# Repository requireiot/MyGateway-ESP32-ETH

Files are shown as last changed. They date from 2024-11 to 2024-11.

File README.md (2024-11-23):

MySensors Ethernet Gateway with ESP32
====

- [MySensors Ethernet Gateway with ESP32](#mysensors-ethernet-gateway-with-esp32)
  - [Objective](#objective)
  - [Features](#features)
  - [Building the Ethernet ESP32 gateway](#building-the-ethernet-esp32-gateway)
    - [Development environment](#development-environment)
    - [Installation](#installation)
    - [Hardware](#hardware)
  - [Modifications to the MySensors library](#modifications-to-the-mysensors-library)
    - [ESP32 gateway via Ethernet](#esp32-gateway-via-ethernet)
    - [Separate tasks for `loop()` and `_process()`](#separate-tasks-for-loop-and-_process)
    - [Connecting the RF24 radio module](#connecting-the-rf24-radio-module)
    - [New notification functions](#new-notification-functions)

## Objective

I needed a gateway that does not depend on a reliable WiFi connection, so Ethernet 
was the only option.

The MySensors website has instructions for how to build an _Ethernet_-based gateway 
(with an ATmega processor) or a gateway using an ESP8266 or ESP32 processor 
(with WiFi connection), but the combination of ESP32 processor and Ethernet connection 
requires some tweaks to the MySensors library, as I found out.

The ESP32 processor is already designed to be used with Ethernet, using a LAN8720 
interface module, which is available from Aliexpress etc. for under €3. This combination 
is well supported by the Arduino universe and the _ETH_ library. To work properly, 
the module needs one minor modification, as described [here](https://mischianti.org/integrating-lan8720-with-esp32-for-ethernet-connectivity-with-plain-http-and-ssl-https/) 
or [here](https://sautter.com/blog/ethernet-on-esp32-using-lan8720/).

## Features

The firmware implements 
* a MySensors _gateway_, that translates between RF24 messages and MQTT messages, 
  like the [example sketch](https://www.mysensors.org/apidocs/GatewayESP32_8ino_source.html) from the MySensors library, or
* a MySensors _repeater_, which re-transmits RF24 messages from a node to the gateway 
  and vice versa

In addition, there are a couple of additional features:

* a simple **Web UI** showing basic information about the device, and statistics 
  about message traffic:
  * IP address and hostname
  * (for a repeater) MySensors Node ID, and the Node ID of the parent
  * Automatic Retry Count (ARC) statistics: the number P of messages sent, the number R 
  of retries needed to succeed, and the "success rate" S = P/(P+R) in percent
  * the total number of messages sent and received, and the number or errors that 
  could not be recovered
  * (for a gateway) the total number of messages sent to and received from the controller
  * finally, a table of the number of messages received from each node, as a total tally, 
  and as an average rate (messages/hour), as well as the "success rate" (see above) for sending messages to each node id
* **over-the-air firmware update** is supported using the standard `ArduinoOTA`library
* an optional **DS18B20 temperature sensor** can be read and reported via MQTT, 
  if (like me) you have concerns about the temperature inside the plastic case of the device.
* A remote **Syslog** message can be sent on startup, which contains
  * code version information
  * IP and MAC address of the unit
  * the reset reason as reported by the ESP firmware

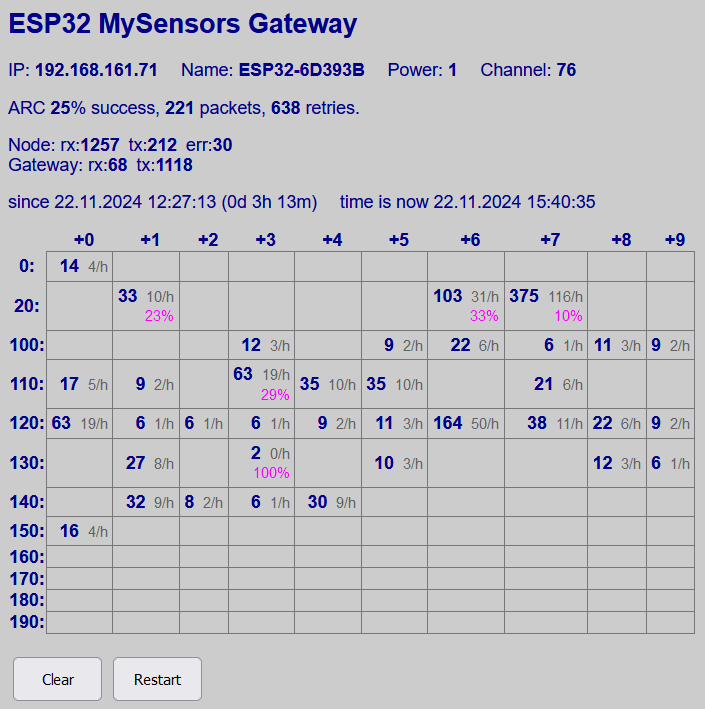
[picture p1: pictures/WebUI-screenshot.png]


Example screenshot from the gateway on my MySensors network. In the table, total number of messages received in **bold**, average number of messages received per hour in gray, and success rate for sending messages to a node in pink.

## Building the Ethernet ESP32 gateway

### Development environment

My development environment consists of Visual Studio Code with the Platformio plugin, 
I don't use the Arduino IDE.

### Installation

1. Clone the repository to your computer
2. copy `src/secrets.sample.h` to `src/secrets.h` and enter your WiFi network name 
   and password there
3. edit `platformio.ini` and set COM port names and IP addresses for your system. (I defined environments for three devices, called esp32-P, esp32-Q and esp32-S, for flashing via a serial interface, and via OTA. Your setup will be different.)
4. at the very start of the `src/main.cpp`, look at the `USE_xxx` constants 
  that enable each feature, comment out the ones you don't want.
5. near the start of `src/main.cpp`, look for the section that starts with 
   `#pragma region configuration` and adjust parameters as needed, e.g. the URL of your syslog server (if you have one), the URL of the MQTT broker, etc.

### Hardware

Schematics are [here](hardware/MyRepeater-ESP32-ETH.pdf). I didn't design 
a PCB, just built the Ethernet version on a prototype board with an ESP32 module 
footprint (called "_7x9cm Prototype PCB For ESP8266 ESP32_" on Aliexpress).

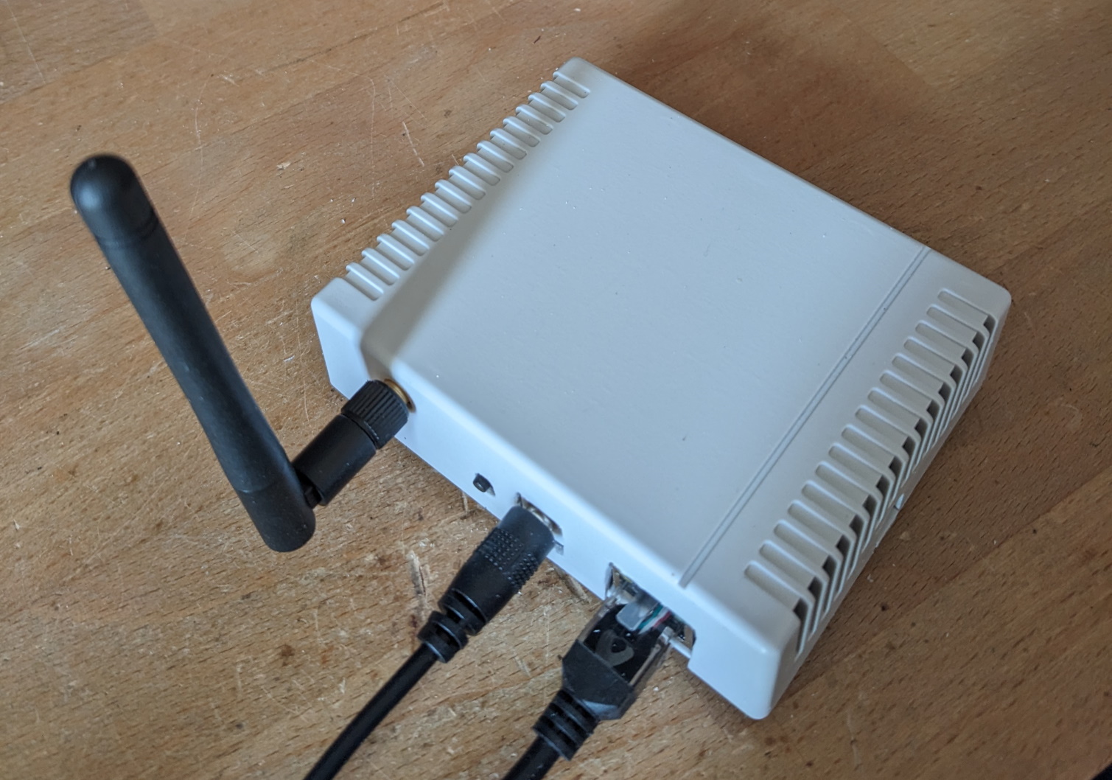
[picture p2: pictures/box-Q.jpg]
 
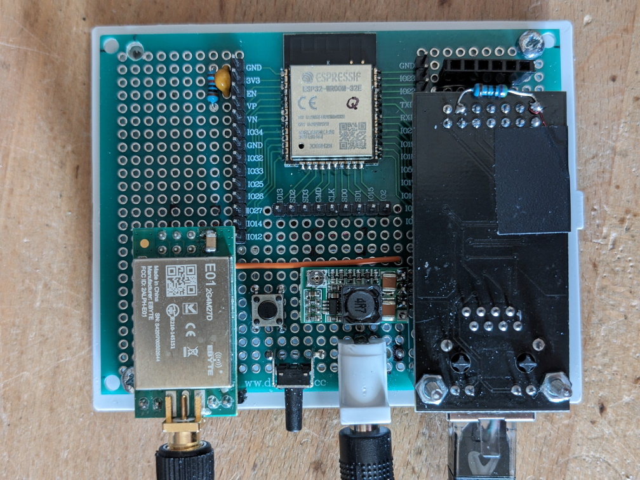
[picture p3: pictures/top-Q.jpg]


The gateway sits next to a Fritzbox 7490 router/DSL modem, connected by a short 
Ethernet cable, and powered from one of the USB ports of the router.

For a small WiFi-based repeater, I used a "mini" module on a piece of normal prototype 
board, placed in a wall wart housing (Reichelt P/N SSG 200 SK-I).

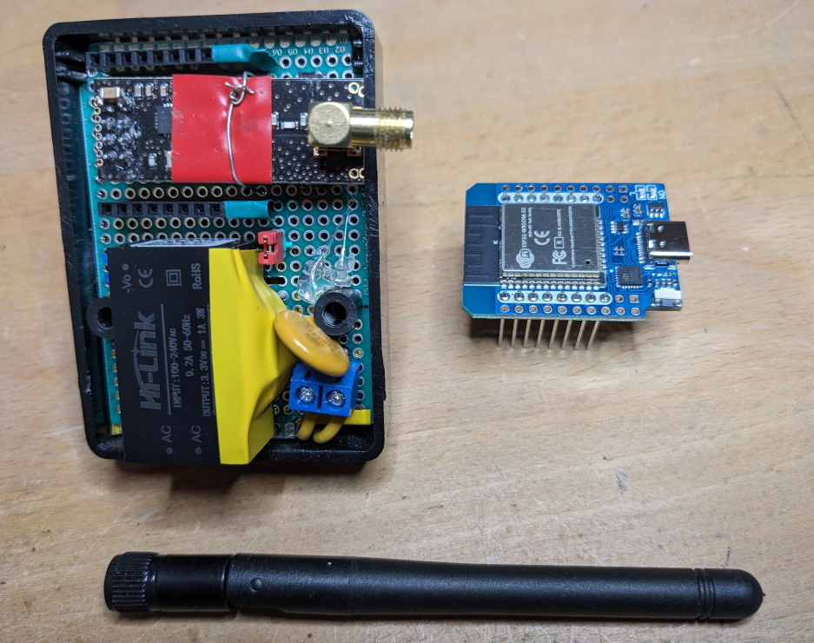
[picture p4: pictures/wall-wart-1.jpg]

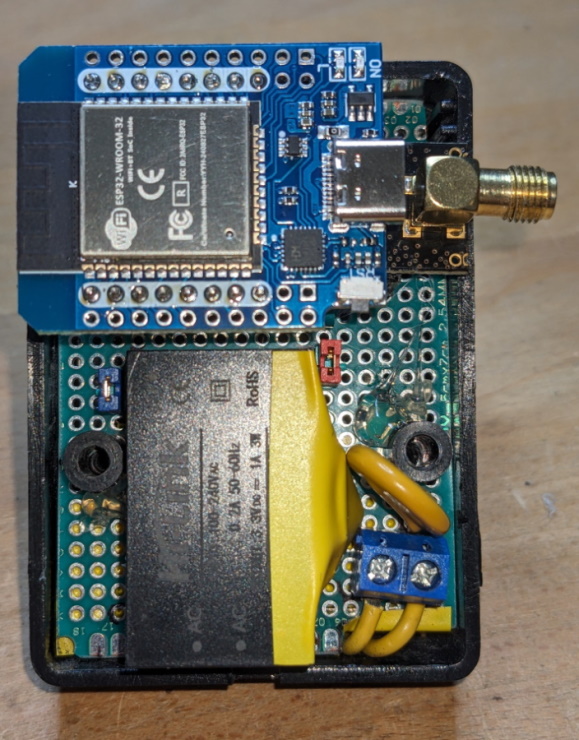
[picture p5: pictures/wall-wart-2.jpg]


## Modifications to the MySensors library

### ESP32 gateway via Ethernet
The MySensors library (version 2.3.2) already contains provisions for an ESP32 based 
gateway, just `#define MY_GATEWAY_ESP32`, and off you go, they even provide an 
[example sketch](https://www.mysensors.org/apidocs/GatewayESP32_8ino_source.html). 
However ... this assumes that the network connection will be via _WiFi_, there is 
no support for a wired Ethernet connection, as far as I can tell.

With my modified version of the MySensors library (included in this repository), 
you either `#define MY_GATEWAY_ESP32_WIFI`, and you get the same behavior as in 
the original, or you `#define MY_GATEWAY_ESP32_ETHERNET` to support a LAN8720 based 
Ethernet interface.

The Ethernet interface must be initialized in _application_ code, ideally before 
the MySensors stuff runs. A good place for this is the `preHwInit()` function 
declared by MySensors as a "weak" function, i.e. it is called early during startup 
if the function is defined in your code, but no error is thrown if you don't define 
a function with this name. See the source code for more details.

### Separate tasks for `loop()` and `_process()`
There are two functions that get called repeatedly during normal operation:
* the Arduino  `loop()` function, which handles all the features implemented by the application
* the MySensors `_process()` function, which handles RF24 communication ... which 
 normally gets called "invisibly" by the MySensors framework

I got the impression that the gateway or repeater runs more reliably (especially 
at lower CPU clock frequencies) if the two functions run in separate tasks, 
so extended calculations or waiting operations in `loop()` won't interfere with 
the regular polling for incoming RF24 packets. 

With my modification to the MySensors library included here, they run in separate 
tasks if the `MY_SEPARATE_PROCESS_TASK` preprocessor macro is defined, e.g. in 
the `platformio.ini` file. Note that both tasks run on the same ESP32 core, the 
other core remains dedicated to networking stuff.

When using separate tasks, the repeater or gateway will work reliably down to 40 MHz CPU frequency (using Ethernet) or 80 MHz (using WiFi).

### Connecting the RF24 radio module

Using the ESP32 Ethernet interface also affects how the NRF24 radio module can be 
connected. You can't use the default SPI port with its default pins on the ESP32, 
because some of those pins are occupied by the Ethernet interface, which, unlike 
other peripherals of the ESP like I2C or SPI, can't have its signals remapped to 
pins of your choice.

Instead of using the default SPI port, a.k.a. SPI3 or SPI(VSPI), we use the "other" 
SPI available on the ESP32, a.k.a. SPI2 or SPI(HSPI). Before you `#include <MySensors.h>`, just say
```
 SPIClass hspi(HSPI);   
 #define RF24_SPI hspi
```
This implies pins MISO=12, MOSI=13, SCK=14, CS=15. I also modified the MySensors 
library so you can `#define` macros named `MY_RF24_MISO_PIN`, `MY_RF24_MOSI_PIN`, 
`MY_RF24_SCK_PIN` and `MY_RF24_CS_PIN`, and the SPI interface will use those custom 
pins if those macros are defined in user code.

### New notification functions
To enable the statistics display, my code must be notified imediately after a message 
has been received (so I can count incoming messages), and after a message has been sent 
(so I can count them, and ask about the number of retries required to successfully 
deliver the message).

Function `void previewMessage(const MyMessage &message)` is called by the modified 
MySensors library right after a message has been received.

Function `void aftertransportSend(const uint8_t nextRecipient, const MyMessage &message)` 
is called by the modified MySensors library right after a message has been sent.

Both functions are declared in the library with the `weak` attribute, i.e. they are 
called if they are defined in the application code, and nothing happens if they are 
not defined in the application code.

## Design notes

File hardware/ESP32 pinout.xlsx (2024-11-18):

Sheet: Sheet1
 |  |  |  |  |  |  |  | WROOM Module
 |  |  |  |  |  |  | GND | Antenna | GND
 |  |  |  |  |  |  | 3V3 |  | io23 | pullup |  | VSPI-MOSI |  | ETH-MDC | ok for GPIO
 |  |  |  |  |  |  | EN |  | io22 | pullup |  | SCL |  | ETH-TX1 | ok for GPIO
 |  | RTC io0 |  |  | ADC1_0 | inp only | io36,VP |  | TxD0
 |  | RTC io3 |  |  | ADC1_3 | inp only | io39,VN |  | RxD0
 |  | RTC io4 |  |  | ADC1_6 | inp only | io34 |  | io21 | pullup |  | SDA |  | ETH-TXEN | ok for GPIO
 |  | RTC io5 |  |  | ADC1_7 | inp only | io35 |  | nc
ok for GPIO |  | RTC io9 | Touch 9 |  | ADC1_4 | no pu | io32 |  | io19 | pullup |  | VSPI-MISO |  | ETH-TX0 | ok for GPIO
ok for GPIO | DS18B20 | RTC io8 | Touch 8 |  | ADC1_5 | no pu | io33 |  | io18 | pullup |  | VSPI-SCK |  | ETH-MDIO | ok for GPIO
ok for GPIO | ETH-RX0 | RTC io6 |  | DAC 1 | ADC2_8 | no pu | io25 |  | io5 | pull-up |  | VSPI-SS |  |  | strapping pin
ok for GPIO | ETH-RX1 | RTC io7 |  | DAC 2 | ADC2_9 | no pu | io26 |  | io17 | pullup |  | TxD 2 |  |  | ok for GPIO | PSRAM SCLK, def Arduino RF24_CE
ok for GPIO | ETH-CRS | RTC io17 | Touch 7 |  | ADC2_7 | no pu | io27 |  | io16 | pullup |  | RxD 2 |  |  | ok for GPIO | PSRAM CE#
output signal at boot | NRF24-SCK | RTC io16 | Touch 6 | MTMS, HSPI-SCK | ADC2_6 | pullup | io14 |  | io4 | pull-down | ADC2_0 |  | Touch 0 | ETH-NC | ok for GPIO
strapping pin | NRF24-MISO | RTC io15 | Touch 5 | MTDI, HSPI-MISO | ADC2_5 | pull-down | io12 |  | io0 | pull-up | ADC2_1 |  | Touch 1 | ETH-REFCLK
 |  |  |  |  |  |  | GND |  | io2 | pull-down | ADC2_2 |  | Touch 2 | NRF24-CE | float or LOW to flash
ok for GPIO | NRF24-MOSI | RTC io14 | Touch 4 | MTCK, HSPI-MOSI | ADC2_4 | pull-down | io13 |  | io15 | pull-up | ADC2_3 | MTDO, HSPI-SS | Touch 3 | NRF24-CS | output signal at boot
 |  |  |  | Flash |  |  | io9 |  | io8 |  |  | Flash
 |  |  |  | Flash |  |  | io10 |  | io7 |  |  | Flash
 |  |  |  | Flash |  |  | io11 |  | io6 |  |  | Flash
 |  |  |  |  |  |  |  |  |  |  |  |  |  | italic : cannot be reassigned
 |  |  |  |  |  |  | Serial 1 default 12,14 must remap
 |  |  |  |  |  |  | Serial 2 default 16,17 can remap

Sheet: I2S
Device | I2C SCL | I2C SDA | mic | mic MCLK | mic BCLK | mic WS | mic DI | I2C addr | spk | spk MCLK | spk BCLK | spk WS | spk DO | I2C addr | AMP ctrl | comments
Inmp441 Max98357a FastLed |  |  | INMP441 |  | 25 | 32 | 33 |  | MAX98357A |  | 14 | 12 | 27
AudioKit | 32 | 33 | ES8388 |  | 27 | 25 |  | 16 | ES8388 |  | 27 | 25 | 26 | 16 | 21 | ESP32A1S V2.2+ variant 1 (ES8388)
ESP32-S3-Box-lite | 18 | 8 | ES7243E | 2 | 17 | 47 | 16 | 16 | ES8156 | 2 | 17 | 47 | 15 | 8 | 46
ESP32-S3-Box | 18 | 8 | ES7210 | 2 | 17 | 47 | 16 |  | ES8311 | 2 | 17 | 47 | 15 | 0x40 | 46

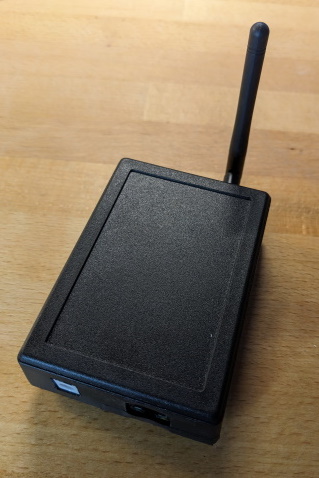
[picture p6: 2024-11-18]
pictures/box-P.jpg

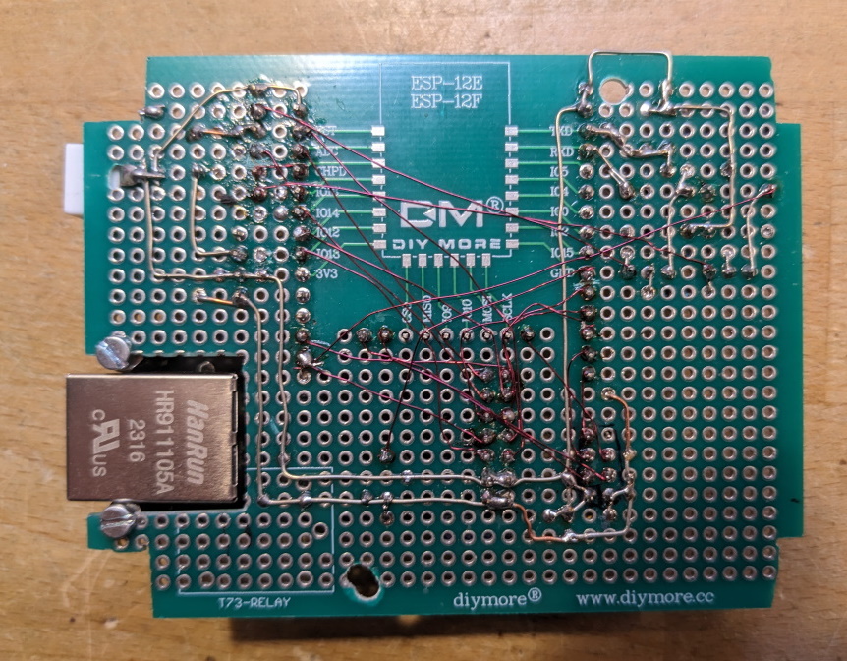
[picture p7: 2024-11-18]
pictures/bottom.jpg

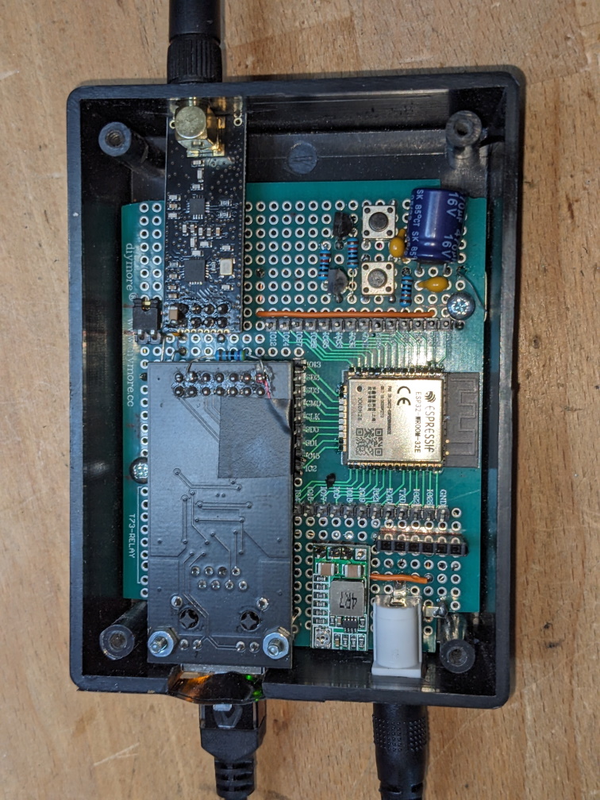
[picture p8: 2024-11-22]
pictures/top-P.jpg

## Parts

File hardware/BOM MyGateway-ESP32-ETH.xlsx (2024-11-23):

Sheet: ETH Gateway «P»
 |  |  |  |  | 11.52 €
 | Price/lot | units/lot | price/unit | units | price
Case 109 x 79 x 32 mm | 2.00 € | 1 | 2.20 € | 1 | 2.20 € | Reichelt 4U32110803000
Prototype PCB 7x9 for ESP | 1.56 € | 1 | 1.56 € | 1 | 1.56 € | Aliexpress "70X90mm Prototype PCB Breadboard Board For ESP"
ESP32 WROOM | 2.36 € | 1 | 2.36 € | 1 | 2.36 € | Aliexpress "ESP32-WROOM-32E"
NRF24L01+ PA LNA | 1.83 € | 1 | 1.83 € | 1 | 1.83 € | Aliexpress https://de.aliexpress.com/item/32330779943.html
LAN8720 Module | 2.35 € | 1 | 2.35 € | 1 | 2.35 € | Aliexpress "Smart Electronics LAN8720 Module, Straight needle"
Female pin header 2x7 | 2.79 € | 400 | 0.01 € | 14 | 0.10 € | Aliexpress
DC-DC converter | 0.64 € | 1 | 0.64 € | 1 | 0.64 € | Aliexpress "Mini DCDC converter 1.8V 2.5V 3.3V 5V 9V 12V"
Barrel jack 5.5/2.1mm print | 1.08 € | 10 | 0.11 € | 1 | 0.11 € | Aliexpress "10PCS Hot Sale DC-005 DC Power Jack Socket5.5x2.1mm"
DS18B20 | 2.49 € | 10 | 0.25 € | 1 | 0.25 € | Aliexpress "DALLAS DS18B20 TO-92 IC Temperature Sensor"
Capacitor 470µF 16V radial | 0.90 € | 10 | 0.09 € | 1 | 0.09 € | Reichelt "RAD 470/16"
Capacitor 100µF 50V SMD 1206 | 2.59 € | 100 | 0.03 € | 1 | 0.03 € | Aliexpress "100pcs 1206 Ceramic Capacitor 50V SMD Thick Film Chip Multilayer 100uF"
Capacitor 100nF 50V SMD 1206 | 0.88 € | 100 | 0.01 € | 1 | 0.01 € | Aliexpress "100pcs 1206 SMD Chip Multilayer Ceramic Capacitor 100nF 50V"

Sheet: WiFi Repeater
 |  |  |  |  | 14.77 €
 | Price/lot | units/lot | price/unit | units | price
Wall wart case | 6.95 € | 1 | 6.95 € | 1 | 6.95 € | Reichelt SSG 200 SK-I
Prototype PCB 4x6cm | 1.43 € | 5 | 0.29 € | 1 | 0.29 € | Aliexpress "Double side Prototype PCB Tinned Universal board 4x6 4*6cm"
D1 Mini ESP32 | 2.59 € | 1 | 2.59 € | 1 | 2.59 € | Aliexpress "D1 MINI ESP32 WiFi+Bluetooth ESP-32 CH9102"
NRF24L01+ PA LNA | 1.83 € | 1 | 1.83 € | 1 | 1.83 € | Aliexpress https://de.aliexpress.com/item/32330779943.html
AC-DC HLK-PM03 | 2.20 € | 1 | 2.20 € | 1 | 2.20 € | Aliexpress "HLK-PM03 (3.3V 3W)"
Female pin header 2x10 | 2.79 € | 400 | 0.01 € | 20 | 0.14 € | Aliexpress
Varistor S14K250 | 0.29 € | 1 | 0.29 € | 1 | 0.29 € | Pollin 94‑221092
Thermo fuse 73°C | 0.48 € | 1 | 0.48 € | 1 | 0.48 € | Pollin 94‑260240

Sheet: ETH Repeater «Q»
 |  |  |  |  | 11.27 €
 | Price/lot | units/lot | price/unit | units | price
Case 109 x 79 x 32 mm | 1.69 € | 1 | 2.20 € | 1 | 2.20 € | Aliexpress "Enclosure Case Plastic Box Circuit Board Project 100x80x29mm, WHITE"
Prototype PCB 7x9 for ESP | 1.56 € | 1 | 1.56 € | 1 | 1.56 € | Aliexpress "70X90mm Prototype PCB Breadboard Board For ESP"
ESP32 WROOM | 2.36 € | 1 | 2.36 € | 1 | 2.36 € | Aliexpress "ESP32-WROOM-32E"
NRF24L01+ PA LNA | 1.83 € | 1 | 1.83 € | 1 | 1.83 € | Aliexpress https://de.aliexpress.com/item/32330779943.html
LAN8720 Module | 2.35 € | 1 | 2.35 € | 1 | 2.35 € | Aliexpress "Smart Electronics LAN8720 Module, Straight needle"
Female pin header 2x7 | 2.79 € | 400 | 0.01 € | 14 | 0.10 € | Aliexpress
DC-DC converter | 0.64 € | 1 | 0.64 € | 1 | 0.64 € | Aliexpress "Mini DCDC converter 1.8V 2.5V 3.3V 5V 9V 12V"
Barrel jack 5.5/2.1mm print | 1.08 € | 10 | 0.11 € | 1 | 0.11 € | Aliexpress "10PCS Hot Sale DC-005 DC Power Jack Socket5.5x2.1mm"
Capacitor 470µF 16V radial | 0.90 € | 10 | 0.09 € | 1 | 0.09 € | Reichelt "RAD 470/16"
Capacitor 100µF 50V SMD 1206 | 2.59 € | 100 | 0.03 € | 1 | 0.03 € | Aliexpress "100pcs 1206 Ceramic Capacitor 50V SMD Thick Film Chip Multilayer 100uF"
Capacitor 100nF 50V SMD 1206 | 0.88 € | 100 | 0.01 € | 1 | 0.01 € | Aliexpress "100pcs 1206 SMD Chip Multilayer Ceramic Capacitor 100nF 50V"

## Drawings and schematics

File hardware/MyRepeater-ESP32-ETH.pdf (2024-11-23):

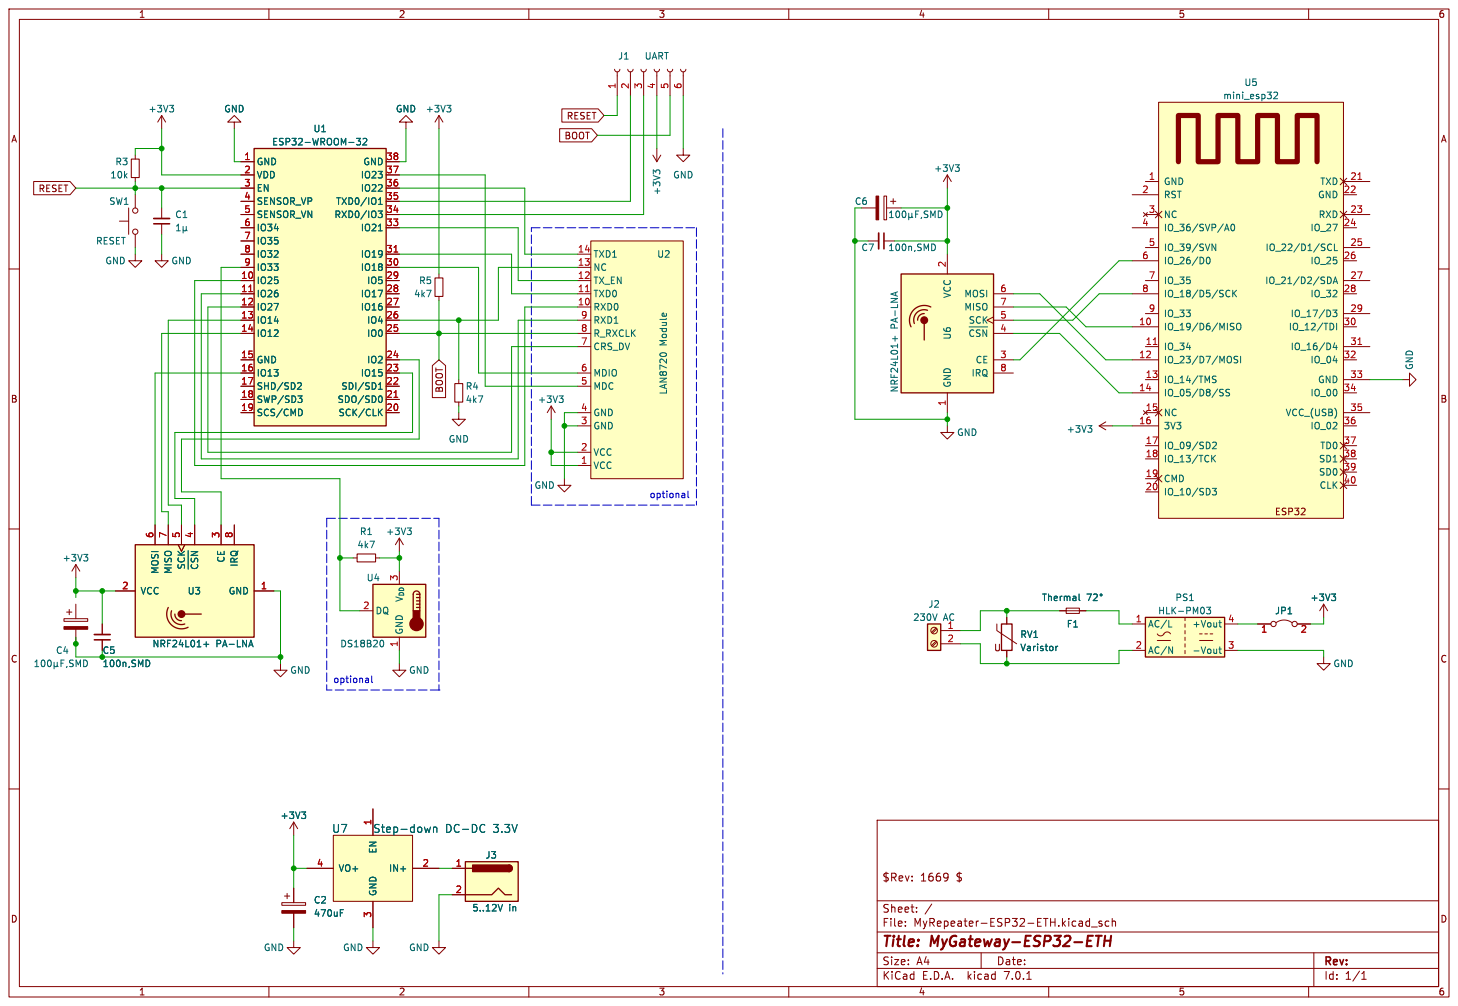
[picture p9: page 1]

2 CE 3 ~{CSN}4 SCK 5 MOSI 6 MISO 7

3 VO+ 4 U7 Step-down DC-DC 3.3V

Id: 1/1 Title: MyGateway-ESP32-ETH

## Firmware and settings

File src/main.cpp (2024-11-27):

/**
 * @file 		  main.cpp
 *
 * Project		: Home automation
 * Author		: Bernd Waldmann
 * Created		: 03-Oct-2024
 * Tabsize		: 4
 * 
 * This Revision: $Id: main.cpp 1684 2024-11-27 11:09:46Z  $
 */

/*
   Copyright (C) 2024 Bernd Waldmann

   This Source Code Form is subject to the terms of the Mozilla Public License, v. 2.0. 
   If a copy of the MPL was not distributed with this file, You can obtain one at http://mozilla.org/MPL/2.0/

   SPDX-License-Identifier: MPL-2.0
*/

/*
  Relies on MySensors, Created by Henrik Ekblad <henrik.ekblad@mysensors.org>.
  Note that the MySensors library is under GPL, so 
  - if you want to combine this source code file with the MySensors library 
    and redistribute it, then read the GPL to find out what is allowed.
  - if you want to combine this file with the MySensors library and only 
    use it at home, then read the GPL to find out what is allowed.
  - if you want to take just this source code, learn from it, modify it, and 
    redistribute it, independent from MySensors, then you have to abide by 
    my license rules (MPL 2.0), which imho are less demanding than the GPL.
 */

/**
 * @brief MySensors gateway or repeater, with ESP32 with LAN8720 Ethernet adapter
*/

//----- some configuration options
// these are defined in platformio.ini, they are specific to each device
// #define USE_ETHERNET    // use Ethernet with LAN8720 rather than WiFi
// #define USE_HSPI        // implies MISO=12 MOSI=13 SCK=14 SS=15
// #define USE_DS18B20     // use temperature sensor
// #define MY_SEPARATE_PROCESS_TASK // loop() and _process() in separate tasks

// these can be enabled here, they are common to all devices
#define USE_SYSLOG      // report to remote syslog server, URL see below
#define USE_NTP         // get time from time server, URL see below
#define USE_HTTP        // enable web UI
#define USE_OTA         // enable over-the-air firmware update

//----- uncomment either of these two, here or in platformio.ini
//#define OPERATE_AS_GATEWAY
//#define OPERATE_AS_REPEATER

//----- the Arduino universe
#include <Arduino.h>
#include <WiFi.h>
#ifdef USE_ETHERNET
 #include <ETH.h>                // LGPLv2.1+ license
#endif
#ifdef USE_SYSLOG
 #include <Syslog.h>             // MIT license, https://github.com/arcao/Syslog
#endif
#ifdef USE_NTP
 #include <NTPClient.h>          // MIT license, https://github.com/arduino-libraries/NTPClient
#endif
#ifdef USE_OTA
 #include <ArduinoOTA.h>         // LGPLv2.1+ license, https://github.com/jandrassy/ArduinoOTA
#endif
#ifdef USE_HTTP 
 #include <WebServer.h>        // LGPLv2.1+ license
#endif
#ifdef USE_DS18B20
 #include <OneWire.h>
 #include <DS18B20.h>           // MIT license, https://github.com/RobTillaart/DS18B20_RT
#endif

//----- the ESP-IDF universe
#include <rom/rtc.h>            // Apache-2.0 license
#include <esp32/clk.h>
#include <esp_pm.h>

//----- my headers
#include "ansi.h"
#include "Revision.h"   // automatically generated header file with SVN revision
#include "secrets.h"    // WiFi password etc

//=====================================================================
#pragma region configuration

// default to repeater operation, unless specified otherwise above or in platformio.ini)
#if !defined(OPERATE_AS_GATEWAY) && !defined(OPERATE_AS_REPEATER)
 #define OPERATE_AS_REPEATER
#endif

#ifdef USE_ETHERNET
 #define IF_NAME "ETH"
#else
 #define ETH WiFi
 #define IF_NAME "WiFi"
#endif

#if defined(USE_ETHERNET) && !defined(USE_HSPI)
 #define USE_HSPI
#endif

//----- pins for LAN8720 Ethernet module
#define PIN_ETH_PHY_POWER   4      // Pin# of the enable for the ext crystal osc, -1 to disable
#define PIN_ETH_PHY_MDC     23      // Pin# of the I²C SCL
#define PIN_ETH_PHY_MDIO    18      // Pin# of the I²C SDA

//----- pin connected to DS18B20 temperature sensor (optional)
#define PIN_DS18B20         33      

//----- pins for SPI connected to NRF24 module
#ifdef USE_HSPI
 #define MY_RF24_CE_PIN      2
 #define MY_RF24_MISO_PIN    12
 #define MY_RF24_MOSI_PIN    13
 #define MY_RF24_SCK_PIN     14
 #define MY_RF24_CS_PIN      15
#else
 #define MY_RF24_CE_PIN     26
 #define MY_RF24_MISO_PIN    19
 #define MY_RF24_MOSI_PIN    23
 #define MY_RF24_SCK_PIN     18
 #define MY_RF24_CS_PIN      5 
#endif

//----- Syslog
#define SYSLOG_SERVER "log-server"
#define SYSLOG_PORT 514
#define SYSLOG_APPNAME "main"

//----- OTA
#define OTA_PASSWORD "123"
#define OTA_PORT    3232

//----- NTP
#define NTP_SERVER  "fritz.box"

//----- MySensors MQTT (only applies to gateway mode)
#define MY_CONTROLLER_URL_ADDRESS "ha-server"
#define MY_MQTT_PUBLISH_TOPIC_PREFIX "my/E/stat"
#define MY_MQTT_SUBSCRIBE_TOPIC_PREFIX "my/cmnd"

#define VERSION "$Id: main.cpp 1684 2024-11-27 11:09:46Z  $ "

#ifdef LED_BUILTIN
 #define LED_INIT   pinMode(LED_BUILTIN,OUTPUT);
 #define TURN_LED_ON     digitalWrite(LED_BUILTIN,HIGH)
 #define TURN_LED_OFF    digitalWrite(LED_BUILTIN,LOW)
#else
 #define LED_INIT
 #define TURN_LED_ON
 #define TURN_LED_OFF
#endif

//---------------------------------------------------------------------
#pragma endregion
//=====================================================================
#pragma region Timing

#define SECONDS		* 1000uL
#define MINUTES 	* 60uL SECONDS
#define HOURS 		* 60uL MINUTES
#define DAYS		* 24uL HOURS

/// minimum time between comms statistics reports
const unsigned long MIN_REPORT_INTERVAL = 60 MINUTES;
/// time between temperature measurements
const unsigned long REPORT_TEMPERATURE_INTERVAL = 30 MINUTES;

//---------------------------------------------------------------------
#pragma endregion
//=====================================================================
#pragma region MySensors

// when using Ethernet, RF24 module must be connected via SPI(2) default pins, 
// because SPI(3) default pins used by LAN8720
#include <SPI.h>
#ifdef USE_HSPI
 SPIClass hspi(HSPI);   // implies MISO=12 MOSI=13 SCK=14 SS=15
 #define RF24_SPI hspi
#else
 SPIClass vspi(VSPI);   // implies MISO=12 MOSI=13 SCK=14 SS=15
 #define RF24_SPI vspi
#endif

#define MY_RADIO_RF24
// with NRF24-PA-LNA module with external antenna, use this setting
// otherwise, too much interference
#define MY_RF24_PA_LEVEL RF24_PA_LOW

#define MY_RF24_SPI_SPEED 1'000'000u
//#define MY_TRANSPORT_WAIT_READY_MS 3000 

// MySensors operating mode
//#define MY_DEBUG
//#define MY_DEBUG_VERBOSE_RF24
#define MY_INDICATION_HANDLER
#define MY_SPLASH_SCREEN_DISABLED

//----- operate as gateway
#ifdef OPERATE_AS_GATEWAY
 #ifdef USE_ETHERNET
  #define MY_GATEWAY_ESP32_ETHERNET
 #else
  #define MY_GATEWAY_ESP32_WIFI
 #endif
 #define MY_GATEWAY_MQTT_CLIENT
 #define FRIENDLY_PROJECT_NAME "ESP32 MySensors Gateway"
 #define NODE_ID_AS_SENSOR MY_NODE_ID
 #define MY_GATEWAY_MAX_CLIENTS 2
 //#define MY_RF24_CHANNEL 99    // test only
#endif

//----- operate as repeater
#ifdef OPERATE_AS_REPEATER
 #define MY_REPEATER_FEATURE
 #define FRIENDLY_PROJECT_NAME "ESP32 MySensors Repeater"
#endif

#include <MySensors.h>

#define SENSOR_ID_ARC		98
#define V_TYPE_ARC			V_VAR5
MyMessage arcMessage = MyMessage(SENSOR_ID_ARC, V_TYPE_ARC);

#define SENSOR_ID_CMND      96

#ifdef USE_DS18B20
 #define SENSOR_ID_TEMP 		41
 MyMessage msgTemperature(SENSOR_ID_TEMP, V_TEMP);
#endif

#define SENSOR_ID_HELLO     95
MyMessage msgHello(SENSOR_ID_HELLO, V_TEXT);

//---------------------------------------------------------------------
#pragma endregion
//=====================================================================
#pragma region Global variables

WiFiUDP udpClient;

#ifdef USE_SYSLOG
 Syslog syslog(udpClient, SYSLOG_SERVER, SYSLOG_PORT, "ESP32", SYSLOG_APPNAME, LOG_USER);
#endif

#ifdef USE_NTP
 NTPClient ntpClient(udpClient,NTP_SERVER);
#endif

#ifdef USE_HTTP 
 WebServer httpServer(80);
#endif

#ifdef USE_DS18B20
 OneWire ow(PIN_DS18B20);
 DS18B20 ds18b20(&ow);
 bool hasDS18B20 = false;
#endif

/// static buffer for assembling various messages
char msgbuf[256];


/// for counting indication() status notifications
struct RxTxStats_t {
	unsigned nRx, nTx, nGwRx, nGwTx, nErr;
} rxtxStats;

/// nMessagesRx[i] counts messages received from node id `i`
unsigned nMessagesRx[256];
/// nMessagesTx[i] counts messages sent to node id `i`
unsigned nMessagesTx[256];
/// nRetries[i] counts mretries required for messages sent to node id `i`
unsigned nRetries[256];

struct ArcStats_t {
    unsigned packets;   ///< number of packets sent
    unsigned retries;   ///< number of retries required
    unsigned success;   ///< success rate in percent
} arcStats;

const char* reset_reasons[] = {
"0: none",
"1: Vbat power on reset",
"2: unknown",
"3: Software reset digital core",
"4: Legacy watch dog reset digital core",
"5: Deep Sleep reset digital core",
"6: Reset by SLC module, reset digital core",
"7: Timer Group0 Watch dog reset digital core",
"8: Timer Group1 Watch dog reset digital core",
"9: RTC Watch dog Reset digital core",
"10: Instrusion tested to reset CPU",
"11: Time Group reset CPU",
"12: Software reset CPU",
"13: RTC Watch dog Reset CPU",
"14: for APP CPU, reseted by PRO CPU",
"15: Reset when the vdd voltage is not stable",
"16: RTC Watch dog reset digital core and rtc module"
};

time_t t_last_clear = 0;

time_t getTimeNow()
{
#ifdef USE_NTP
    return ntpClient.getEpochTime();
#else
    return time(nullptr);
#endif
}

//---------------------------------------------------------------------
#pragma endregion
//=====================================================================
#pragma region ARC statistics

/**
 * @brief Collect statistics re Automatic Retries Count (ARC) for RF24.
 * Call this function immediately after each `send()` call.
 * 
 * @return int  number of retries required for most recent send
 * 
 */
int collectArcStatistics()
{
	int rssi = transportHALGetSendingRSSI();	// boils down to (-29 - (8 * (RF24_getObserveTX() & 0xF)))
	int arc = (-(rssi+29))/8;
	arcStats.packets++;         // # of packets sent
	arcStats.retries += arc;    // # of retries required
    arcStats.success = 
        arcStats.packets ? 
            (100uL * arcStats.packets) / (arcStats.packets + arcStats.retries) 
            : 100;
    return arc;
}


/**
 * @brief Reset all statistics counters to zero. Do this every hour or so
 * 
 */
void initStats()
{
	memset( nMessagesRx, 0, sizeof(nMessagesRx));
	memset( nMessagesTx, 0, sizeof(nMessagesTx));
	memset( nRetries, 0, sizeof(nRetries));
	memset( &rxtxStats, 0, sizeof(rxtxStats) );
    memset( &arcStats, 0, sizeof arcStats );
    t_last_clear = getTimeNow();
}


/**
 * @brief Send JSON-esque message with error statistics, then reset counters.
 * Error statistics include # of packets sent, # of retries required, success rate
 * Call this once per hour or so
 * 
 * @return const char* pointer to string sent to MySensors, like "{P:100;R:10;S:90}"
 *
 * Success rate:
 * 5 packets 0 retries = 100%
 * 5 packets 5 retries = 50%
 * 5 packets 20 retries = 20%
 */
const char* reportArcStatistics()
{
	//              				    1...5...10...15...20...25 max payload
	//				                    |   |    |    |    |    |
	static char payload[26];	//      {P:65535;R:65535;S:100}
	snprintf(payload, sizeof payload, "{P:%u,R:%u,S:%u}",
        arcStats.packets, arcStats.retries, arcStats.success );

    //memset( &arcStats, 0, sizeof arcStats );
	arcMessage.setSensor(SENSOR_ID_ARC).setType(V_TYPE_ARC);
	delay(10);
    send(arcMessage.set(payload));
	return payload;
}

//---------------------------------------------------------------------
#pragma endregion
//=====================================================================
#pragma region OTA

#ifdef USE_OTA

void setupOTA()
{
//----- configure Over-The-Air updates
	ArduinoOTA.setPort( OTA_PORT );
	ArduinoOTA.setPassword( OTA_PASSWORD );
    ArduinoOTA.setHostname( ETH.getHostname());
    
	ArduinoOTA.onStart([]() {
		Serial.println("ArduinoOTA start");
	});
	ArduinoOTA.onEnd([]() {
		Serial.println("\nArduinoOTA end");
	});
	ArduinoOTA.onProgress([](unsigned int progress, unsigned int total) {
		Serial.printf("OTA Progress: %u%%\r", (progress / (total / 100)));
	});
	ArduinoOTA.onError([](ota_error_t error) {
		Serial.printf("Error[%u]: ", error);
		if (error == OTA_AUTH_ERROR) {
			Serial.println("Auth Failed");
		} else if (error == OTA_BEGIN_ERROR) {
			Serial.println("Begin Failed");
		} else if (error == OTA_CONNECT_ERROR) {
			Serial.println("Connect Failed");
		} else if (error == OTA_RECEIVE_ERROR) {
			Serial.println("Receive Failed");
		} else if (error == OTA_END_ERROR) {
			Serial.println("End Failed");
		}
	});
	ArduinoOTA.begin();
}

#endif // USE_OTA

//---------------------------------------------------------------------
#pragma endregion
//=====================================================================
#pragma region Webserver

#ifdef USE_HTTP 


const char index_html[] PROGMEM = R"rawliteral(
<!DOCTYPE HTML><html>
<head>
  <title>%TITLE%</title>
  <style>
    body { background-color: #cccccc; font-family: Arial, Helvetica, Sans-Serif; Color: #000088; line-height: 1.1; }
    table { border-collapse: collapse; }
    td { text-align: right; border: 1px solid #777777; padding: 4px; }
    button { margin: 5px; padding:10px; min-height:20px; min-width: 80px; float:left; }
    .mph { color: #606060; font-size:smaller; }
    .suc { color: #fc03fc; font-size:smaller; }
  </style>
</head>
<body>
  <h2>%TITLE%</h2>
  <p>
    IP:<b>%IPADDR%</b>&emsp;
    Name:<b>%HOSTNAME%</b>&emsp;
    Channel:<b>%CHANNEL%</b>&emsp;
    Power:<b>%POWER%</b>&emsp;
)rawliteral"

#ifdef OPERATE_AS_REPEATER
 R"rawliteral(
    Node:<b>%NODEID%</b>&emsp;
    Parent:<b>%PARENT%</b>&emsp;
 )rawliteral"
#endif

R"rawliteral(
  </p>  
  <p>
    ARC <b>%SUCCESS%</b>%% success, <b>%PACKETS%</b> packets, <b>%RETRIES%</b> retries.&emsp;
  </p>
  <p>
    Node rx:<b>%NRX%</b>&ensp;tx:<b>%NTX%</b>&ensp;err:<b>%NERR%</b> (<b>%ERROR_RATE%</b>%%)&emsp;
)rawliteral"

#ifdef OPERATE_AS_GATEWAY
 R"rawliteral(
    Gateway: rx:<b>%NGWRX%</b>&ensp;tx:<b>%NGWTX%</b>
 )rawliteral"
#endif

R"rawliteral(
  </p>
  <p>
    since %LASTCLEAR% (%ELAPSED%)&emsp;
    time is now %NOW%
  </p>
  <p>%TABLE%</p>
  <form action="/clear"><button type="submit">Clear</button></form>
  <form action="/reboot"><button type="submit">Restart</button></form>
</body>
</html>
)rawliteral";


/**
 * @brief Convert unsigned int to string
 */
String utos( unsigned u )
{
    static char buf[10];
    utoa(u,buf,10);
    return String(buf);
}


/**
 * @brief Generate one HTML table row, #of messages received from nodes (y)..(y+9)
 * 
 * @param y 
 * @return String 
 */
String make_table_row(unsigned y, time_t nSecsElapsed)
{
    unsigned x, totalMsgsRx, MsgsPerHour, totalMsgsTx, totalRetries, success;

    String s = "<tr><th>" + utos(y) + ":</td>";
    for (x=0; x<10; x++) {

        totalMsgsRx = nMessagesRx[y + x];
        if (nSecsElapsed)
            MsgsPerHour = (totalMsgsRx * 3600uL) / nSecsElapsed;
        s += "<td>";
        if (totalMsgsRx > 0) {
            s += "<b>" + utos(totalMsgsRx) + "</b>";
            if (nSecsElapsed)
                s += "&ensp;<span class='mph'>" + utos(MsgsPerHour) + "/h</span>";
        }
        totalMsgsTx = nMessagesTx[y+x];
        if (totalMsgsTx > 0) {
            totalRetries = nRetries[y+x];
            success = (100 * totalMsgsTx) / (totalMsgsTx + totalRetries);
            s += "<br/><span class='suc'>" + utos(success) + "%</span>";
        }
        s += "</td>";
    }
    s += "</tr>\n";
    return s;
}


/**
 * @brief Generate HTML table with statistics (# of messages received per node)
 * 
 * @return String 
 */
String make_table() 
{
    String s;
    unsigned x,y;
    time_t nSecsElapsed = getTimeNow() - t_last_clear;

    s = "<table><tr><th> </th>";
    for (x=0; x<10; x++) s += "<th>&ensp;+" + utos(x) + "</th>";
    s += "</tr>\n";
    s += make_table_row(0,nSecsElapsed);
    s += make_table_row(20,nSecsElapsed);
    for (y=100; y<200; y+=10) {
        s += make_table_row(y,nSecsElapsed);
    }
    s += "</table>";
    return s;
}


/**
 * @brief Poor man's templating engine: replace keywords with content
 * 
 * @param var       the keyword that was enclosed in %...%
 * @return String   the replacement
 */
String processor(const String& var)
{
    if (var.length()==0) return "%";

    //----- static device information
    if (var=="IPADDR") return ETH.localIP().toString();
    if (var=="HOSTNAME") return ETH.getHostname();
    if (var=="NODEID") return String(MY_NODE_ID);
    if (var=="VERSION") return String(VERSION);
    if (var=="PARENT") return String(transportGetParentNodeId());
    //----- configuration
    if (var=="POWER") return String(MY_RF24_PA_LEVEL);
    if (var=="CHANNEL") return String(MY_RF24_CHANNEL);

    //-----indication-based counts
    // # of messages received via network
    if (var=="NRX") return String(rxtxStats.nRx);
    // # of messages sent via network
    if (var=="NTX") return String(rxtxStats.nTx);
    // # of messages failed to send via network
    if (var=="NERR") return String(rxtxStats.nErr);
    // # of messages received from controller, as gateway
    if (var=="NGWRX") return String(rxtxStats.nGwRx);
    // # of messages sent to controller, as gateway
    if (var=="NGWTX") return String(rxtxStats.nGwTx);
    // percentage of messages attempted to send that could not be sent
    if (var=="ERROR_RATE") return String( rxtxStats.nTx ? (100 * rxtxStats.nErr)/rxtxStats.nTx : 0 );

    //----- ARC statistics
    if (var=="PACKETS") return String(arcStats.packets);
    if (var=="RETRIES") return String(arcStats.retries);
    if (var=="SUCCESS") return String(arcStats.success);

    //----- general information
    if (var=="TITLE") return FRIENDLY_PROJECT_NAME ;
    if (var=="NOW") {
        time_t epoch = getTimeNow();
        strftime(msgbuf, sizeof msgbuf, "%d.%m.%Y %H:%M:%S", localtime(&epoch));
        return String(msgbuf);
    }
    if (var=="LASTCLEAR") {
        strftime(msgbuf, sizeof msgbuf, "%d.%m.%Y %H:%M:%S", localtime(&t_last_clear));
        return String(msgbuf);
    }
    if (var=="ELAPSED") {
        time_t t_elapsed = getTimeNow() - t_last_clear; // in seconds
        tm* te = gmtime(&t_elapsed);
        snprintf(msgbuf,sizeof msgbuf, "%dd %dh %dm", te->tm_yday, te->tm_hour, te->tm_min);
        return String(msgbuf);
    }
    //----- the biggie: table of messages vs node id
    if (var=="TABLE") return make_table();
    return String();
}


#define CHAR_BEGIN_VAR '%'
#define CHAR_END_VAR '%'

/**
 * @brief Poor man's templating engine: find all keywords 
 * 
 * @param tpl      the HTML with embedded keywords enclosed in %...%
 * @return String  final HTML
 */
static String process( const String& tpl )
{
    String res = "";
    int p1,p2;

    p1 = tpl.indexOf(CHAR_BEGIN_VAR);
    p2 = 0;
    while (p1 != -1) {
        res += tpl.substring(p2,p1);
        p2 = tpl.indexOf(CHAR_END_VAR,p1+1);
        if (p2 != -1) {
            res += processor( tpl.substring(p1+1,p2) );
        }
        p1 = tpl.indexOf(CHAR_BEGIN_VAR,p2+1);
        p2++;
    }
    res += tpl.substring(p2);
    return res;
}


 void setupHTTPServer()
 {
    // Route for root / web page
    httpServer.on( "/", HTTP_GET, []() {
        log_i("HTTP '/'");
        httpServer.send(200, "text/html", process(index_html));
    });
    httpServer.on("/clear", HTTP_GET, [] () {
        log_i("HTTP '/clear'");
        initStats();
        httpServer.sendHeader("Location", "/",true);  
        httpServer.send(302, "text/plain", "");
    });
    httpServer.on("/reboot", HTTP_GET, [] () {
        log_i("HTTP '/reboot'");
        httpServer.sendHeader("Location", "/",true);  
        httpServer.send(302, "text/plain", "");
        ESP.restart();
    });
    httpServer.onNotFound( [] () {
        log_e("HTTP not found");
        httpServer.send(404, "text/plain", "not found");
    });
    // Start server
    httpServer.begin();
 }
#endif // USE_HTTP

//---------------------------------------------------------------------
#pragma endregion
//=====================================================================
#pragma region Network event handler
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
void loop() 
{
    unsigned long t_now = millis();
 
#if defined( USE_HTTP) 
    httpServer.handleClient();
#endif

#ifdef USE_OTA
    ArduinoOTA.handle();
#endif

#ifdef USE_NTP
    ntpClient.update();
#endif

#ifdef USE_DS18B20
    // report module temperature
	static unsigned long t_lastTemperatureReport=0;
	if ((unsigned long)(t_now - t_lastTemperatureReport) > REPORT_TEMPERATURE_INTERVAL) {
		t_lastTemperatureReport=t_now;
        reportTemperature();
    }
#endif

    // every now and then, report ARC statistics ("pseudo-RSSI")
	static unsigned long t_lastReport=0;
	if ((unsigned long)(t_now - t_lastReport) > MIN_REPORT_INTERVAL) {
		t_lastReport=t_now;
        wait(1);
        const char* arc = reportArcStatistics();
        log_i("ARC: %s",arc);
        //initStats();
	}

#ifdef LED_BUILTIN
    // blink LED
    static unsigned t_last_LED=0;
	if ((unsigned long)(t_now - t_last_LED) > 50uL) {
		t_last_LED=t_now;
        unsigned t = t_now & 0x3FF; // count up to ~1000ms
        if (t < 50) TURN_LED_ON; else TURN_LED_OFF;
    }
#endif
}

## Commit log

2024-11-18 folder MySensors now is a fork of original, with ESP32-Ethernet support added
2024-11-23 updated schematic and BOM
    [BOM MyGateway-ESP32-ETH.xlsx, MyRepeater-ESP32-ETH.kicad_sch]
